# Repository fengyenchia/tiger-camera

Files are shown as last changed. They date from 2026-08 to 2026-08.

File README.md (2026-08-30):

# Tiger Camera

一台結合 ESP32-S3-CAM、手機後製與公開相簿的 DIY 相機，讓每次按下快門都能留下可下載、可分享的照片。

Tiger Camera 以 ESP32-S3-CAM 與 OV2640 為核心，拍照後透過 Wi-Fi 暫存照片。使用者掃描機身 NFC、輸入螢幕上的領取碼，就能直接在手機瀏覽器完成後製、下載，或將成品公開到網站相簿。

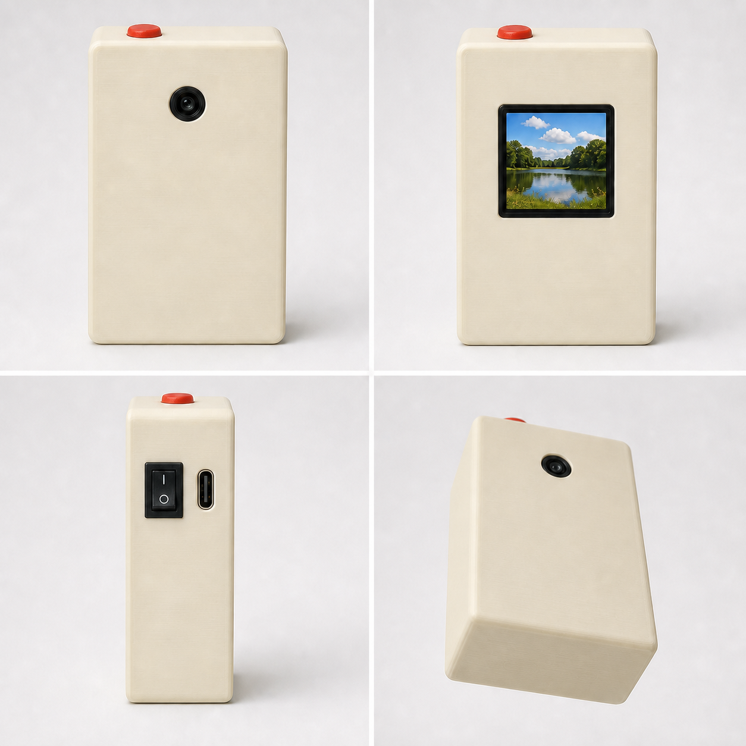
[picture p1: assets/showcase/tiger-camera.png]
Tiger Camera 外觀示意圖


## 核心特色

- 短按快門即可拍攝 JPEG，並在小型 TFT 螢幕上回顧照片
- 透過 2.4 GHz Wi-Fi 上傳私人照片草稿
- NFC 開啟領取頁，再以六位領取碼取得自己的照片
- 手機瀏覽器直接後製，不需要安裝 App
- 可選擇：
  - 拍立得白邊框
  - 拍攝日期與時間
  - 自訂文字或可愛預設文字
  - 直式 3:4、橫式 4:3、方形 1:1
  - 多種可愛風格濾鏡
- 完成圖可下載，也可以選擇公開到相簿
- 公開相片支援放大檢視與下載
- 原始照片只作為私人暫存，永久保存的是後製完成圖

## 功能

### 相機端

- 實體快門短按拍攝 JPEG，拍攝後立即在 ST7735 螢幕回顧
- 以 PSRAM 保留最新一張照片；下一次成功拍攝時覆蓋上一張
- 顯示 Wi-Fi、上傳與電池狀態，網路暫時中斷時不影響基本拍照
- 連線至指定的 2.4 GHz Wi-Fi，不需要相機自行建立 Wi-Fi 熱點

### 網站端

- NFC 導向領取頁，輸入相機顯示的六位領取碼即可取得照片
- 在手機瀏覽器完成裁切比例、拍立得框、日期、文字與風格處理
- 支援直式 3:4、橫式 4:3、方形 1:1，不改變原照片方向
- 成品可直接下載；公開後會出現在公開相簿並可放大檢視與下載
- 原始照片只在領取與後製期間保存；網站永久保存後製成品
- 公開相簿由管理員維護，管理員可重新命名或永久刪除公開照片

## 網站

- 公開網站：[tiger-camera.fengyenchia.com](https://tiger-camera.fengyenchia.com)
- 使用流程：開啟網站的 `/create` 頁面 → 輸入相機顯示的六位領取碼 → 後製 → 下載或公開
- 公開相簿：[tiger-camera.fengyenchia.com/gallery](https://tiger-camera.fengyenchia.com/gallery)

### 網站畫面

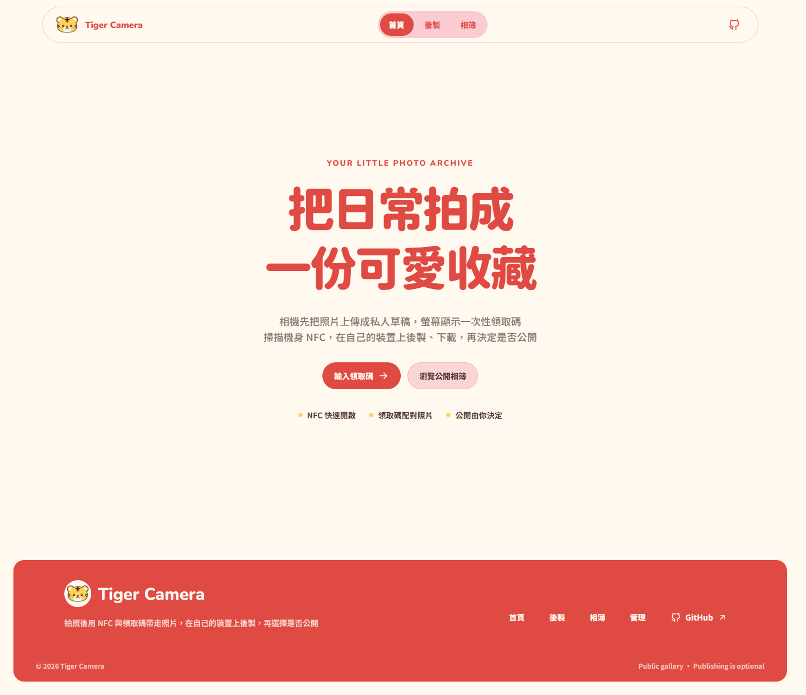
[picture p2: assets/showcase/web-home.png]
Tiger Camera 首頁


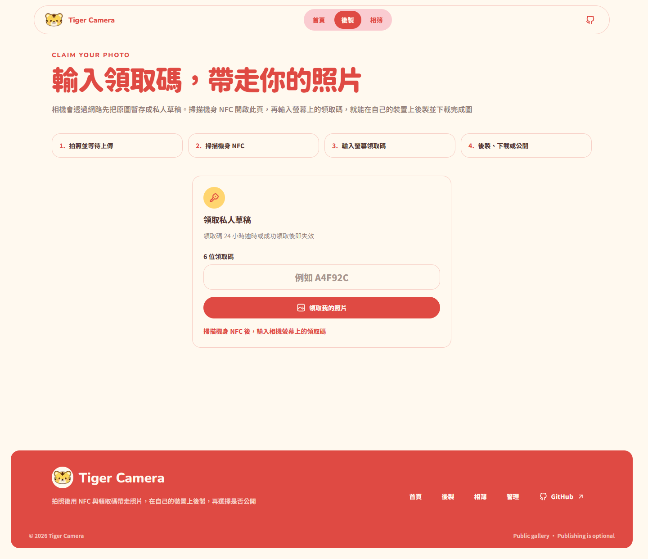
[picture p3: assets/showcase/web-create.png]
Tiger Camera 領取與後製頁


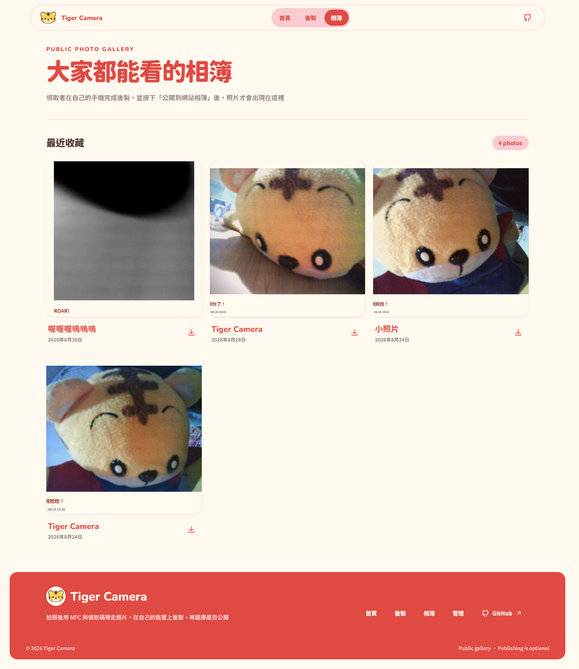
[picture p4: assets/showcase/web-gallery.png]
Tiger Camera 公開相簿


## 使用流程

```text
按下快門
    ↓
相機拍攝並連線上傳私人草稿
    ↓
掃描 NFC，開啟 Tiger Camera 網站
    ↓
輸入螢幕上的六位領取碼
    ↓
在手機選擇版型、文字與濾鏡
    ↓
下載完成圖，或公開到相簿
```

領取碼是照片配對用的一次性代碼；照片在領取前保持私人狀態，公開與否由領取者決定。

## 照片資料流程

```text
1. 按下相機快門
   ↓
2. ESP32-S3-CAM 擷取 JPEG，暫存在 PSRAM
   ↓
3. 相機以固定的裝置上傳 Token，透過 HTTPS 上傳私人草稿
   ↓
4. Backend 將原圖存入 Cloudflare R2，並在 Neon 建立草稿 metadata
   ↓
5. Backend 回傳六位領取碼；相機將領取碼顯示在螢幕上
   ↓
6. 使用者掃描 NFC、開啟 /create，輸入領取碼
   ↓
7. Backend 核發該照片的一次性領取權杖，瀏覽器取得私人原圖
   ↓
8. 使用者在手機 Canvas 完成裁切、框線、日期、文字與濾鏡
   ↓
9. 使用者下載成品，或明確選擇公開
   ↓
10. 公開時 Backend 儲存後製 JPEG、更新 metadata，並刪除私人原圖
   ↓
11. 公開相片出現在 /gallery；訪客可檢視與下載
```

原圖只用於領取與後製，不作為公開相簿內容；若使用者只下載、不公開，原圖仍會依草稿保存期限清理。

## 技術組成

| 部分 | 使用技術 |
| --- | --- |
| 相機硬體 | ESP32-S3-WROOM-1-N16R8、OV2640、ST7735 TFT、實體快門 |
| 韌體 | Arduino-ESP32、PlatformIO、PSRAM JPEG buffer |
| 前端 | Next.js、React、TypeScript、Tailwind CSS、shadcn/ui、Canvas API |
| 後端 | Next.js Route Handlers、Neon Serverless PostgreSQL、Cloudflare R2 |
| 儲存 | 原圖私人暫存；後製完成圖永久保存 |
| 電源 | 803040 LiPo、TP4056、MT3608、KCD1-11 |

## 環境需求與安裝

- Node.js 20 或以上
- pnpm 9 或以上（專案目前使用 pnpm workspace）
- 現代瀏覽器（Chrome、Edge、Safari 或 Firefox）
- 若要執行完整後端：Neon Serverless PostgreSQL 與 Cloudflare R2

在專案根目錄安裝 Web workspace 依賴：

```powershell
cd web
pnpm install
```

## 快速開始

需要 Frontend／Backend 各自的本機環境變數。請勿將密碼、Token 或雲端金鑰提交到 Git。

```powershell
cd web
pnpm install
pnpm dev
```

這會同時啟動 Frontend（`http://localhost:3000`）與 Backend（`http://localhost:3001`）。若只想啟動單一服務，也可以使用 `pnpm dev:frontend` 或 `pnpm dev:backend`。若只想查看公開介面，也可以直接使用正式網站連結。

## 部署設定

正式環境需要在部署平台設定環境變數，至少包含：

- Frontend API base URL
- Backend 公開 API URL
- Neon 資料庫連線字串
- Cloudflare R2 endpoint、bucket 與存取金鑰
- 管理員登入驗證設定
- 相機使用的固定 `DEVICE_UPLOAD_TOKEN`

這些值只應放在本機 `.env.local` 或 Vercel 等部署平台的環境變數設定中。README 不提供實際金鑰、密碼或 Token；`.gitignore` 會忽略本機秘密檔案。

## 專案結構

```text
tiger-camera/
├── firmware/
│   └── tiger-camera-v1/
│       ├── include/       # 腳位、相機、螢幕、快門、電池與網路模組
│       ├── src/           # Arduino-ESP32 韌體程式
│       ├── boards/        # ESP32-S3-CAM 板型設定
│       └── platformio.ini # PlatformIO 建置設定
├── web/
│   ├── frontend/          # 公開 Next.js 網站與手機後製介面
│   │   ├── app/           # 首頁、領取後製頁、公開相簿、管理頁
│   │   ├── api/           # Axios 前端呼叫層
│   │   ├── components/    # 共用 UI 與網站元件
│   │   └── lib/           # Canvas 圖片處理
│   ├── backend/           # 獨立部署的 Next.js API
│   │   ├── app/api/       # Route Handlers 與 API 文件頁
│   │   └── lib/           # Neon、R2、驗證與伺服器邏輯
├── enclosure/             # 外殼 CAD、STL、量測與參考圖
├── assets/                # 展示圖片與共用資產
│   └── showcase/          # README 使用的產品／網站截圖
├── bom/                   # 材料與採購清單
└── README.md              # 公開產品介紹
```

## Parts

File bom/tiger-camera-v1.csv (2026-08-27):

已購買 | category | item | recommended_model_or_keyword | detailed_specification | quantity | stage | unit_price_twd | subtotal_twd | required | listing_type | seller_or_source | shopee_url | shopee_search_url | checked_date | arrival_check | notes
V | 核心 | ESP32-S3-CAM 主板＋鏡頭 | AroundTW／GOOUUU ESP32-S3-CAM N16R8＋OV2640 | ESP32-S3-WROOM-1-N16R8；16MB Flash；8MB Octal PSRAM；OV2640 2MP；2.4GHz Wi-Fi；OTG與TTL雙USB-C；板載microSD | 1 | 先買 | 420 | 420 | yes | 直接商品頁雙相機選項 | 環島科技 | https://shopee.tw/%E3%80%90%E7%92%B0%E5%B3%B6%E7%A7%91%E6%8A%80%E3%80%91ESP32-S3-CAM-%E6%A0%B8%E5%BF%83%E9%96%8B%E7%99%BC%E6%9D%BF-%E5%8F%B0%E7%81%A3%E7%8F%BE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 | https://shopee.tw/search?keyword=ESP32-S3-CAM%20N16R8%20OV2640 | 2026-08-11 | 確認選OV2640而非OV3660；記錄PCB與N16R8標示；測TTL及OTG燒錄；韌體確認16MB Flash與8MB PSRAM | 商品頁價格區間NT$420至480；OV2640預算先列420；主板未標示LiPo充電；不得沿用AI-Thinker pinout
V | 核心 | ST7735 SPI 螢幕 | 實機 ST7735 128x128 SPI 無觸控 | 實機面板為128×128；3.3V邏輯；INITR_144GREENTAB；BGR；inversion off；面板吋數與PCB尺寸待卡尺量測 | 1 | 已驗收 | 180 | 180 | yes | 三選項商品頁 | 樂意創客官方店 | https://shopee.tw/%E3%80%90%E6%A8%82%E6%84%8F%E5%89%B5%E5%AE%A2%E5%AE%98%E6%96%B9%E5%BA%97%E3%80%91%E3%80%8A%E9%99%84%E7%99%BC%E7%A5%A8%E3%80%8B1.8%E5%90%8B-1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 | https://shopee.tw/search?keyword=ST7735%20128x128%20SPI | 2026-08-24 | 已重新確認RGB色條與方形即時預覽；仍需量螢幕對角與PCB長寬 | 實機面板是128×128；賣場共用128×160標題不可作為實機規格；外殼不可用未量測尺寸鎖定
V | 核心 | 快門按鍵（四腳版） | 6x6x5mm 四腳輕觸開關／TS-1187A 類 | 常開瞬時四腳穿孔按鍵；另購相容按鍵帽可改善手感 | 2 | 先買 | 5 | 10 | yes | 蝦皮搜尋頁 | 電子材料賣家 | https://shopee.tw/search?keyword=6x6x5mm%20%E8%BC%95%E8%A7%B8%E9%96%8B%E9%97%9C | https://shopee.tw/search?keyword=6x6x5mm%20%E8%BC%95%E8%A7%B8%E9%96%8B%E9%97%9C | 2026-08-28 | 用萬用電表確認兩側接腳與按下導通；接GPIO1與GND | 保留作為開發版或小體積安裝方案
V | 核心 | 快門按鍵（面板版） | 060009 兩腳面板固定式自復位按鈕（125V 3A） | 兩腳無正負極；螺牙加螺帽固定；按下導通且放開復位；外殼開孔尺寸仍以實物量測 | 1 | 已驗收 |  |  | conditional | 蝦皮搜尋頁 | 電子材料賣家 | https://shopee.tw/search | https://shopee.tw/search | 2026-08-28 | 已接GPIO1與GND實測；按一下成功拍照且放開復位；E0仍須量螺牙直徑、面板開孔及後方深度 | 與四腳版並列保留；125V 3A是開關接點額定標示，不是本專案供電電壓
V | 開發 | 接線與麵包板 | 400孔麵包板＋2.54mm 杜邦線＋短跳線 | 公對公／公對母線；保持 TFT SPI 線短 | 1批 | 先買 | 100 | 100 | conditional | 蝦皮搜尋頁 | 台灣出貨電子材料賣家 | https://shopee.tw/search | https://shopee.tw/search | 2026-08-11 | 抽查導通與夾持力；TFT 線先控制在10cm內 | 已有庫存可省
V | 分享 | NFC 被動貼紙 | NTAG213 圓形防水貼紙（我買 NTAG215） | NDEF可寫入；保存 https://tiger-camera.fengyenchia.com/create；不需相機端NFC硬體 | 1 | NFC階段 | 20 | 20 | yes | 蝦皮搜尋頁 | 台灣出貨 NFC 賣家 | https://shopee.tw/search?keyword=NTAG213%20NFC%20%E8%B2%BC%E7%B4%99 | https://shopee.tw/search?keyword=NTAG213%20NFC%20%E8%B2%BC%E7%B4%99 | 2026-08-11 | 用 NFC Tools 寫入並以 iPhone／Android 各測一次；不要先永久鎖定 | NFC 只開啟正式網站；每張照片領取碼顯示在相機螢幕
 | 儲存 | microSD 記憶卡 | 4GB microSD／FAT32 選配 | 只在需要相機端關機保存／離線JSON／裝置端多照片相簿時購買；GPIO38至40保留給板載SD | 1 | 未來選配 | 100 | 100 | no | 蝦皮搜尋頁 | 可靠品牌賣家 | https://shopee.tw/search?keyword=4GB%20microSD%20FAT32 | https://shopee.tw/search?keyword=4GB%20microSD%20FAT32 | 2026-08-11 | 完整讀寫測試並確認與TFT及快門共存 | V1不買；裝置最新照片只存PSRAM；雲端永久相簿不依賴microSD；未來可再依實機確認支援容量
v | 電源 | LiPo 電池 | 環島科技 803040 3.7V 1000mAh 單節聚合物鋰電池 | 標稱3.7V滿電4.2V；標準充電0.5C/500mA；最大充電1C/1A；最大放電1C/1A；保護IC允許最大電流2A；尺寸8.0±0.3×30±0.5×40±1mm，含保護板與導線可能更長 | 1 | P0已選 | 220 | 220 | yes | 蝦皮商品頁 | 環島科技 | https://shopee.tw/%E3%80%90%E7%92%B0%E5%B3%B6%E7%A7%91%E6%8A%80%E3%80%913.7V-%E8%81%9A%E5%90%88%E7%89%A9%E9%8B%B0%E9%9B%BB%E6%B1%A0-803040-%E5%8F%B0%E7%81%A3%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 | https://shopee.tw/search?keyword=803040%201000mAh%203.7V%20%E9%8B%B0%E9%9B%BB%E6%B1%A0 | 2026-08-24 | 商品規格已提供：標準充電0.5C/500mA、最大充電1C/1A、最大放電1C/1A、保護IC允許最大電流2A；到貨仍確認實物標籤、保護板、接頭、極性與尺寸；先量到貨電壓再接模組 | 803040厚度較503040增加約3mm；容量提高但外殼與電池艙需重新量測
v | 電源 | LiPo充電板 | 環島科技 TP4056 Type-C 1A 鋰電池充電保護二合一 | Type-C輸入；商品標示1A；電池最大充電1A；4.2V CC/CV與保護 | 1 | P0已選 | 10 | 10 | yes | 蝦皮商品頁 | 環島科技 | https://shopee.tw/%E3%80%90%E7%92%B0%E5%B3%B6%E7%A7%91%E6%8A%80%E3%80%91%E6%96%B0%E6%AC%BETP4056-1A%E9%8B%B0%E9%9B%BB%E6%B1%A0%E5%85%85%E9%9B%BB%E6%9D%BF%E6%A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 | https://shopee.tw/search?keyword=TP4056%20Type-C%20500mA%20%E9%8B%B0%E9%9B%BB%E6%B1%A0 | 2026-08-24 | 首次量測實際充電電流與溫度；燙手就停止
v | 電源 | 5V升壓板 | 環島科技 MT3608 DC-DC 2A可調升壓模組 | 輸入2至24V；輸出可調；使用前先以萬用電表調至5.0V；2A為賣家最大標稱 | 1 | P0已選 | 15 | 15 | yes | 蝦皮商品頁 | 環島科技 | https://shopee.tw/-%E7%92%B0%E5%B3%B6%E7%A7%91%E6%8A%80-MT3608-DC-DC%E5%8D%87%E5%A3%93%E6%A8%A1%E5%A1%8A2A%E5%8D%87%E5%A3%93%E6%9D%BF%E8%BC%B8%E5%85%A5%E9%9B%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 | https://shopee.tw/search?keyword=MT3608%205V%20%E5%8D%87%E5%A3%93 | 2026-08-24 | 開機前先量空載5V；切斷升壓輸入的電源開關需放在TP4056與MT3608之間
v | 電源 | 電源開關 | 環島科技 KCD1-11 小船型 1P 三腳開關 | 商品標示3A/250V、6A/125V；確認腳位後以中間／切換腳控制MT3608 IN+；第三腳依版本用途處理 | 1 | P0已選 | 15 | 15 | yes | 蝦皮商品頁 | 環島科技 | https://shopee.tw/%E3%80%90%E7%92%B0%E5%B3%B6%E7%A7%91%E6%8A%80-%E5%B0%8F%E8%88%B9%E5%9E%8B%E9%96%8B%E9%97%9C-%E5%B0%8F%E5%B0%8F%E6%B4%9B%E5%8F%AF%E9%96%8B%E9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 | https://shopee.tw/search?keyword=KCD1-11%20%E9%96%8B%E9%97%9C | 2026-08-24 | 外殼需開矩形孔；先以DT-830D通斷檔確認腳位；不可只依外觀接線
v | 電源 | 電池電壓分壓組 | 100kΩ×2（0.1µF陶瓷電容選配） | KCD1-11開關後正極經100kΩ到GPIO3；GPIO3再經100kΩ到OUT-/GND；不可從常時帶電OUT+直接送入GPIO；不能直接接LiPo到GPIO | 1組 | P0.1 | 5 | 5 | yes | 電子材料搜尋頁 | 台灣電子材料賣家 | https://shopee.tw/search?keyword=100k%20%E9%9B%BB%E9%98%BB | https://shopee.tw/search?keyword=100k%20%E9%9B%BB%E9%98%BB | 2026-08-27 | 用萬用電表確認阻值；接線後驗證10次冷啟動與TFT讀值 | GPIO3為strapping pin；0.1µF可不裝；只可用高阻抗分壓並以DT-830D校正
 | 外殼 | M2 五金 | M2 熱熔螺母 OD3.2×L3mm＋M2 機牙螺絲組 | M2×6／8／10mm 少量；先印孔徑測試片 | 1批 | CAD後 | 120 | 120 | yes | 蝦皮搜尋頁 | 3D列印五金賣家 | https://shopee.tw/search | https://shopee.tw/search | 2026-08-11 | 先印孔徑測試片再鎖定 CAD 孔位 | 基本兩片式相機殼不做角色裝飾
 | 外殼 | 透明保護片 | PET透明片0.3至0.5mm | 可裁切；螢幕可視區需無霧化與刮痕 | 1 | CAD後 | 50 | 50 | no | 蝦皮搜尋頁 | 模型材料賣家 | https://shopee.tw/search?keyword=PET%20%E9%80%8F%E6%98%8E%E7%89%87%200.5mm | https://shopee.tw/search?keyword=PET%20%E9%80%8F%E6%98%8E%E7%89%87%200.5mm | 2026-08-11 | 在亮屏上檢查反光／霧度 | 螢幕內縮且受保護時可省
 | 外殼 | 3D列印材料 | PETG 1.75mm 少量或外包基本殼 | 兩片式矩形功能殼；先用現有材料或外包小量列印 | 1批 | 功能完成後 | 300 | 300 | yes | 蝦皮搜尋頁 | 3D列印耗材或代印賣家 | https://shopee.tw/search?keyword=PETG%201.75mm%203D%E5%88%97%E5%8D%B0%20%E4%BB%A3%E5%8D%B0 | https://shopee.tw/search?keyword=PETG%201.75mm%203D%E5%88%97%E5%8D%B0%20%E4%BB%A3%E5%8D%B0 | 2026-08-11 | 先印平面定位板與功能殼 | 已有耗材可省；不做虎頭造型可顯著減少列印量

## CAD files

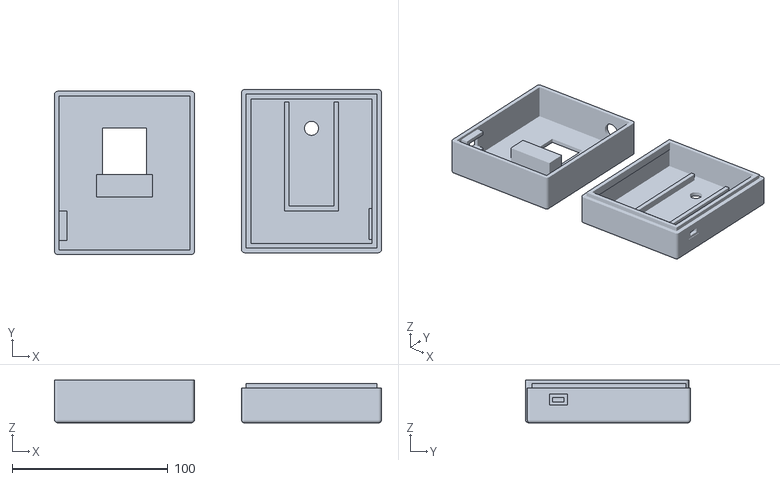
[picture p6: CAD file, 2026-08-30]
enclosure/stl/v1.stl
210.2 x 106.2 x 27.6

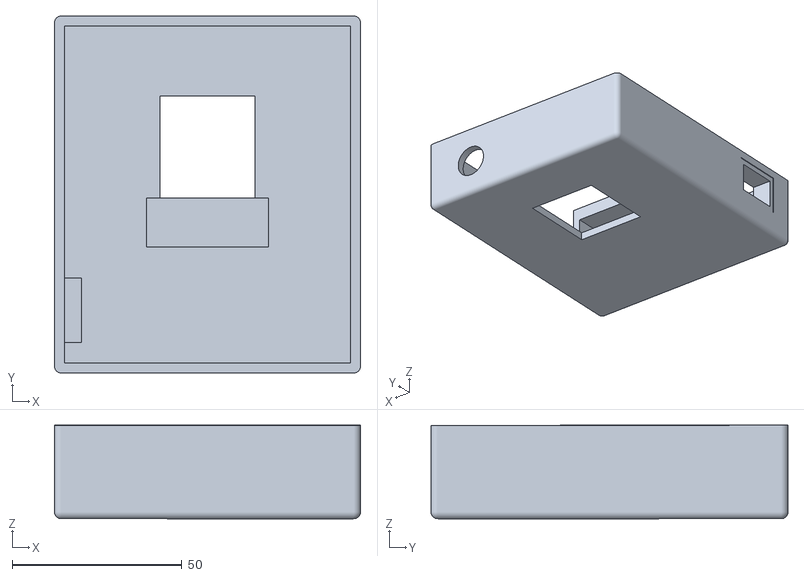
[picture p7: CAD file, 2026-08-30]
enclosure/stl/後蓋.stl
90.0 x 105.0 x 27.5

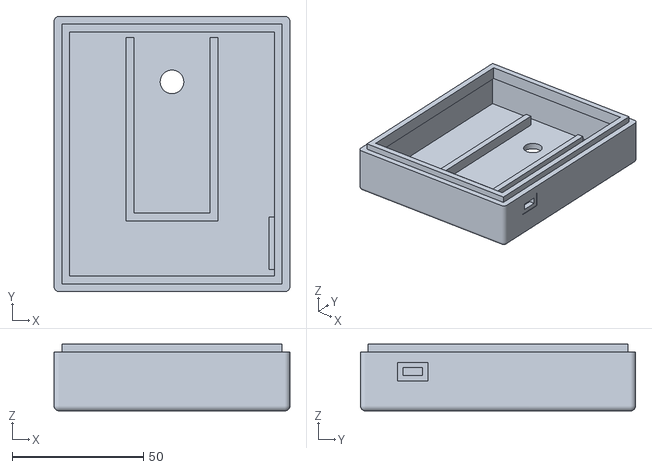
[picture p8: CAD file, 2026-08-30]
enclosure/stl/前蓋.stl
90.0 x 105.0 x 25.5

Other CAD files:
enclosure/v1.blend

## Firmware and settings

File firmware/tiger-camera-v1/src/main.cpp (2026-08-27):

#include <Arduino.h>
#include "esp_heap_caps.h"

#include "app_config.h"
#include "battery_monitor.h"
#include "board_pins.h"
#include "camera_controller.h"
#include "display_controller.h"
#include "latest_photo_buffer.h"
#include "network_manager.h"
#include "shutter_button.h"
#include "upload_manager.h"

enum class CameraState {
  booting,
  liveView,
  capturing,
  copying,
  review,
  uploadNotice,
  claimReady,
  error,
};

CameraController camera;
DisplayController display;
LatestPhotoBuffer latestPhoto;
NetworkManager network;
UploadManager uploader;
ShutterButton shutter(BoardPins::shutter, AppConfig::shutterDebounceMs);
BatteryMonitor battery(BoardPins::batterySense);

CameraState state = CameraState::booting;
unsigned long stateStartedMs = 0;
unsigned long lastPreviewMs = 0;
uint32_t latestUploadGeneration = 0;
bool latestClaimAvailable = false;
char latestClaimCode[7] = {};
char latestClaimExpiresAt[25] = {};

void enterState(CameraState next) {
  state = next;
  stateStartedMs = millis();
}

void printMemoryReport() {
  Serial.printf("[board] flash: %u bytes\n",
                static_cast<unsigned>(ESP.getFlashChipSize()));
  Serial.printf("[board] psram detected: %s\n", psramFound() ? "yes" : "no");
  Serial.printf("[board] psram total: %u bytes\n",
                static_cast<unsigned>(ESP.getPsramSize()));
  Serial.printf("[board] psram free: %u bytes\n",
                static_cast<unsigned>(heap_caps_get_free_size(MALLOC_CAP_SPIRAM)));
  Serial0.printf("[board] flash: %u bytes\n",
                 static_cast<unsigned>(ESP.getFlashChipSize()));
  Serial0.printf("[board] psram detected: %s\n", psramFound() ? "yes" : "no");
  Serial0.printf("[board] psram total: %u bytes\n",
                 static_cast<unsigned>(ESP.getPsramSize()));
  Serial0.printf(
      "[board] psram free: %u bytes\n",
      static_cast<unsigned>(heap_caps_get_free_size(MALLOC_CAP_SPIRAM)));
}

void showLatestPhoto() {
  if (!latestPhoto.lock(pdMS_TO_TICKS(1000))) {
    display.showStatus("BUFFER BUSY");
    delay(1000);
    enterState(CameraState::error);
    return;
  }

  const bool rendered = display.drawJpeg(latestPhoto.dataUnsafe(),
                                         latestPhoto.sizeUnsafe());
  latestPhoto.unlock();
  if (!rendered) {
    display.showStatus("JPEG ERROR");
    delay(1000);
    enterState(CameraState::error);
    return;
  }
  const BatteryReading& batteryReading = battery.reading();
  display.showBatteryOverlay(batteryReading.volts, batteryReading.percent,
                             batteryReading.valid);
  enterState(CameraState::review);
}

void pollUploadResult() {
  uint32_t generation = 0;
  char claimCode[7] = {};
  char expiresAt[25] = {};
  if (!uploader.takeClaimCode(&generation, claimCode, sizeof(claimCode),
                              expiresAt, sizeof(expiresAt))) {
    return;
  }
  if (generation != latestUploadGeneration) {
    Serial.printf("[upload] ignored stale claim generation=%lu latest=%lu\n",
                  generation, latestUploadGeneration);
    Serial0.printf("[upload] ignored stale claim generation=%lu latest=%lu\n",
                   generation, latestUploadGeneration);
    return;
  }
  strlcpy(latestClaimCode, claimCode, sizeof(latestClaimCode));
  strlcpy(latestClaimExpiresAt, expiresAt, sizeof(latestClaimExpiresAt));
  latestClaimAvailable = true;
}

void showUploadNotice() {
  const UploadStatus uploadStatus = uploader.status();
  switch (uploadStatus.phase) {
    case UploadPhase::waitingForWifi:
      display.showStatus("WAITING WIFI", "photo kept");
      delay(1000);
      break;
    case UploadPhase::waitingForTime:
      display.showStatus("SYNCING TIME", "photo kept");
      delay(1000);
      break;
    case UploadPhase::configurationError:
      display.showStatus("UPLOAD OFF", "check secrets");
      delay(1000);
      break;
    case UploadPhase::authenticationError:
      display.showStatus("DEVICE ERROR", "credential");
      delay(1000);
      break;
    case UploadPhase::serverRejected:
      display.showStatus("UPLOAD ERROR", "check serial");
      delay(1000);
      break;
    case UploadPhase::memoryError:
      display.showStatus("UPLOAD ERROR", "photo kept");
      delay(1000);
      break;
    case UploadPhase::retrying:
      display.showStatus("UPLOAD RETRY", "photo kept");
      delay(1000);
      break;
    default:
      display.showStatus("UPLOADING", "private draft");
      delay(1000);
      break;
  }
  enterState(CameraState::uploadNotice);
}

void showLatestClaim() {
  display.showClaimCode(latestClaimCode);
  Serial.printf("[claim] code=%s expires=%s\n", latestClaimCode,
                latestClaimExpiresAt);
  Serial0.printf("[claim] code=%s expires=%s\n", latestClaimCode,
                 latestClaimExpiresAt);
  enterState(CameraState::claimReady);
}

void capturePhoto() {
  latestClaimAvailable = false;
  enterState(CameraState::capturing);
  display.showStatus("CAPTURING");
  delay(1000);

  if (AppConfig::captureFrameSize != AppConfig::previewFrameSize) {
    if (!camera.setFrameSize(AppConfig::captureFrameSize)) {
      display.showStatus("CAMERA ERROR", "resolution");
      delay(1000);
      enterState(CameraState::error);
      return;
    }

    // Only discard transition frames when the sensor mode actually changes.
    camera.flushFrames(AppConfig::captureSettleFrames);
  }
  camera_fb_t* frame = camera.acquireFrame();
  if (frame == nullptr || frame->format != PIXFORMAT_JPEG || frame->len == 0) {
    const char* reason = frame == nullptr
                             ? "no framebuffer"
                             : (frame->format != PIXFORMAT_JPEG ? "not JPEG"
                                                                : "empty JPEG");
    Serial.printf("[photo] capture failed: %s\n", reason);
    Serial0.printf("[photo] capture failed: %s\n", reason);
    camera.releaseFrame(frame);
    if (AppConfig::captureFrameSize != AppConfig::previewFrameSize) {
      camera.setFrameSize(AppConfig::previewFrameSize);
      camera.flushFrames(AppConfig::previewSettleFrames);
    }
    display.showStatus("CAPTURE ERROR", reason);
    delay(1000);
    enterState(CameraState::error);
    return;
  }

  enterState(CameraState::copying);
  const size_t capturedSize = frame->len;
  const uint16_t capturedWidth = frame->width;
  const uint16_t capturedHeight = frame->height;
  const uint32_t capturedMillis = millis();
  const bool copied = latestPhoto.replace(frame->buf, frame->len);

  // The camera framebuffer is returned only after the JPEG is fully copied.
  camera.releaseFrame(frame);
  if (AppConfig::captureFrameSize != AppConfig::previewFrameSize) {
    camera.setFrameSize(AppConfig::previewFrameSize);
    camera.flushFrames(AppConfig::previewSettleFrames);
  }

  if (!copied) {
    display.showStatus("PSRAM ERROR", "old photo kept");
    delay(1000);
    enterState(CameraState::error);
    return;
  }

  Serial.printf("[photo] captured %ux%u %u bytes; free PSRAM %u bytes\n",
                static_cast<unsigned>(capturedWidth),
                static_cast<unsigned>(capturedHeight),
                static_cast<unsigned>(capturedSize),
                static_cast<unsigned>(
                    heap_caps_get_free_size(MALLOC_CAP_SPIRAM)));
  Serial0.printf("[photo] captured %ux%u %u bytes; free PSRAM %u bytes\n",
                 static_cast<unsigned>(capturedWidth),
                 static_cast<unsigned>(capturedHeight),
                 static_cast<unsigned>(capturedSize),
                 static_cast<unsigned>(
                     heap_caps_get_free_size(MALLOC_CAP_SPIRAM)));

  // A successful local capture invalidates every older claim immediately,
  // even if allocating the new upload snapshot fails.
  latestUploadGeneration = UINT32_MAX;
  bool queued = false;
  if (latestPhoto.lock(pdMS_TO_TICKS(1000))) {
    queued = uploader.queuePhoto(
        latestPhoto.dataUnsafe(), latestPhoto.sizeUnsafe(), capturedWidth,
        capturedHeight, capturedMillis, &latestUploadGeneration);
    latestPhoto.unlock();
  }
  if (!queued) {
    Serial.println("[upload] could not queue photo; local JPEG remains available");
    Serial0.println("[upload] could not queue photo; local JPEG remains available");
  }
  showLatestPhoto();
}

void drawLivePreview() {
  camera_fb_t* frame = camera.acquireFrame();
  if (frame == nullptr) {
    Serial.println("[preview] frame unavailable");
    return;
  }
  if (frame->format == PIXFORMAT_JPEG) {
    display.drawJpeg(frame->buf, frame->len);
    const BatteryReading& batteryReading = battery.reading();
    display.showBatteryOverlay(batteryReading.volts, batteryReading.percent,
                               batteryReading.valid);
  }
  camera.releaseFrame(frame);
}

void setup() {
  Serial.begin(115200);

  // 等待 USB 串口連線成功（最多等 3 秒避免卡死）
  unsigned long start = millis();
  while (!Serial && (millis() - start < 3000)) {
    delay(10);
  }

  Serial.println("ESP32-S3 Camera Booting...");

  Serial0.begin(115200);
  delay(800);

  display.begin();
  battery.begin();

  // ─── 頁面 1: 四色色塊測試（停留 1 秒）───
  display.showColorTest();
  delay(1000);

  // ─── 頁面 2: 品牌主視覺（停留 2.0 秒）───
  display.showSplashPage("TIGER CAM", "by Yen-Chia Feng");
  delay(2000);

  // ─── 頁面 3: 終端機 Log 與逐項初始化 ───
  display.showBootLogPage();
  delay(400);

  // 1. PSRAM 檢測
  if (!psramFound() || ESP.getPsramSize() == 0) {
    display.appendBootLog("PSRAM", "FAIL", 25);
    delay(1500);
    display.showStatus("PSRAM ERROR", "not detected");
    enterState(CameraState::error);
    return;
  }
  display.appendBootLog("PSRAM", "OK", 25);
  printMemoryReport();
  delay(600);

  // 2. 緩衝區初始化
  if (!latestPhoto.begin()) {
    display.appendBootLog("BUFFER", "FAIL", 50);
    delay(1500);
    display.showStatus("MUTEX ERROR");
    enterState(CameraState::error);
    return;
  }
  display.appendBootLog("BUFFER", "OK", 50);
  delay(600);

  // 3. 網路與上傳管理器
  network.begin();
  if (!uploader.begin(&network)) {
    Serial.println("[upload] background task unavailable; camera remains local-only");
    Serial0.println("[upload] background task unavailable; camera remains local-only");
  }
  display.appendBootLog("NETWORK", "OK", 75);
  delay(600);

  // 4. OV2640 相機模組
  if (!camera.begin()) {
    display.appendBootLog("CAMERA", "FAIL", 100);
    delay(1500);
    display.showStatus("CAMERA ERROR", "init failed");
    enterState(CameraState::error);
    return;
  }
  display.appendBootLog("CAMERA", "OK", 100);
  delay(1000);

  // ─── 完成並提示拍照 ───
  shutter.begin();
  display.showStatus("READY", "press shutter");
  delay(1800);
  shutter.discardPending();
  enterState(CameraState::liveView);
}

void loop() {
  const unsigned long now = millis();
  battery.loop();
  network.loop();
  pollUploadResult();

  if (state == CameraState::liveView) {
    if (latestClaimAvailable) {
      showLatestClaim();
      return;
    }
    if (shutter.pressed()) {
      capturePhoto();
      return;
    }
    if (now - lastPreviewMs >= AppConfig::previewIntervalMs) {
      lastPreviewMs = now;
      drawLivePreview();
    }
    return;
  }

  if (state == CameraState::review &&
      now - stateStartedMs >= AppConfig::reviewDurationMs) {
    // Capturing and review intentionally ignore presses and switch bounce.
    shutter.discardPending();
    if (latestClaimAvailable) {
      showLatestClaim();
    } else {
      showUploadNotice();
    }
    return;
  }

  if (state == CameraState::uploadNotice &&
      now - stateStartedMs >= AppConfig::uploadNoticeDurationMs) {
    shutter.discardPending();
    if (latestClaimAvailable) {
      showLatestClaim();
    } else {
      enterState(CameraState::liveView);
    }
    return;
  }

  if (state == CameraState::claimReady) {
    // The first press dismisses the code and returns to live view. A later
    // press from live view captures the next photo, preventing an accidental
    // shot while the owner is only trying to leave the claim screen.
    if (shutter.pressed()) {
      latestClaimAvailable = false;
      enterState(CameraState::liveView);
    }
    return;
  }

  if (state == CameraState::error &&
      now - stateStartedMs >= AppConfig::errorDurationMs) {
    if (esp_camera_sensor_get() != nullptr) {
      camera.setFrameSize(AppConfig::previewFrameSize);
      camera.flushFrames(AppConfig::previewSettleFrames);
      shutter.discardPending();
      enterState(CameraState::liveView);
    }
  }

  delay(5);
}

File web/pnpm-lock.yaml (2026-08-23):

lockfileVersion: '9.0'

settings:
  autoInstallPeers: true
  excludeLinksFromLockfile: false

importers:

  .: {}

  backend:
    dependencies:
      '@aws-sdk/client-s3':
        specifier: ^3.1110.0
        version: 3.1110.0
      '@aws-sdk/s3-request-presigner':
        specifier: ^3.1110.0
        version: 3.1110.0
      '@neondatabase/serverless':
        specifier: ^1.1.0
        version: 1.1.0
      bcryptjs:
        specifier: ^3.0.3
        version: 3.0.3
      jose:
        specifier: ^6.2.8
        version: 6.2.8
      next:
        specifier: 16.3.0
        version: 16.3.0(@babel/core@7.29.7)(@types/node@20.19.43)(react-dom@19.2.8(react@19.2.8))(react@19.2.8)
      next-swagger-doc:
        specifier: ^0.4.1
        version: 0.4.1(next@16.3.0(@types/node@20.19.43)(react-dom@19.2.8(react@19.2.8))(react@19.2.8))(openapi-types@12.1.3)
      react:
        specifier: 19.2.8
        version: 19.2.8
      react-dom:
        specifier: 19.2.8
        version: 19.2.8(react@19.2.8)
      server-only:
        specifier: ^0.0.1
        version: 0.0.1
      swagger-ui-dist:
        specifier: ^5.32.13
        version: 5.32.13
    devDependencies:
      '@types/node':
        specifier: ^20
        version: 20.19.43
      '@types/react':
        specifier: ^19
        version: 19.2.18
      '@types/react-dom':
        specifier: ^19
        version: 19.2.4(@types/react@19.2.18)
      '@types/swagger-ui-dist':
        specifier: ^3.30.6
        version: 3.30.6
      eslint:
        specifier: ^9
        version: 9.39.5(jiti@2.7.0)
      eslint-config-next:
        specifier: 16.3.0
        version: 16.3.0(eslint@9.39.5(jiti@2.7.0))(typescript@5.1.3)
      typescript:
        specifier: ^5.1.3
        version: 5.1.3

  frontend:
    dependencies:
      '@radix-ui/react-checkbox':
        specifier: ^1.3.11
        version: 1.3.11(@types/react-dom@19.2.4(@types/react@19.2.18))(@types/react@19.2.18)(react-dom@19.2.8(react@19.2.8))(react@19.2.8)
      '@radix-ui/react-dialog':
        specifier: ^1.1.23
        version: 1.1.23(@types/react-dom@19.2.4(@types/react@19.2.18))(@types/react@19.2.18)(react-dom@19.2.8(react@19.2.8))(react@19.2.8)
      '@radix-ui/react-radio-group':
        specifier: ^1.4.7
        version: 1.4.7(@types/react-dom@19.2.4(@types/react@19.2.18))(@types/react@19.2.18)(react-dom@19.2.8(react@19.2.8))(react@19.2.8)
      '@radix-ui/react-select':
        specifier: ^2.3.7
        version: 2.3.7(@types/react-dom@19.2.4(@types/react@19.2.18))(@types/react@19.2.18)(react-dom@19.2.8(react@19.2.8))(react@19.2.8)
      '@radix-ui/react-slider':
        specifier: ^1.4.7
        version: 1.4.7(@types/react-dom@19.2.4(@types/react@19.2.18))(@types/react@19.2.18)(react-dom@19.2.8(react@19.2.8))(react@19.2.8)
      '@tabler/icons-react':
        specifier: ^3.46.0
        version: 3.46.0(react@19.2.8)
      axios:
        specifier: ^1.19.0
        version: 1.19.0(supports-color@7.1.0)
      class-variance-authority:
        specifier: ^0.7.1
        version: 0.7.1
      clsx:
        specifier: ^2.1.1
        version: 2.1.1
      motion:
        specifier: ^13.1.0
        version: 13.1.0(react-dom@19.2.8(react@19.2.8))(react@19.2.8)
      next:
        specifier: 16.3.0
        version: 16.3.0(@babel/core@7.29.7)(@types/node@20.19.43)(react-dom@19.2.8(react@19.2.8))(react@19.2.8)
      react:
        specifier: 19.2.8
        version: 19.2.8
      react-dom:
        specifier: 19.2.8
        version: 19.2.8(react@19.2.8)
      tailwind-merge:
        specifier: ^3.6.0
        version: 3.6.0
    devDependencies:
      '@tailwindcss/postcss':
        specifier: ^4
        version: 4.3.3
      '@types/node':
        specifier: ^20
        version: 20.19.43
      '@types/react':
        specifier: ^19
        version: 19.2.18
      '@types/react-dom':
        specifier: ^19
        version: 19.2.4(@types/react@19.2.18)
      eslint:
        specifier: ^9
        version: 9.39.5(jiti@2.7.0)(supports-color@7.1.0)
      eslint-config-next:
        specifier: 16.3.0
        version: 16.3.0(@typescript-eslint/parser@8.66.0(eslint@9.39.5(jiti@2.7.0)(supports-color@7.1.0))(supports-color@7.1.0)(typescript@5.1.3))(eslint@9.39.5(jiti@2.7.0)(supports-color@7.1.0))(supports-color@7.1.0)(typescript@5.1.3)
      tailwindcss:
        specifier: ^4
        version: 4.3.3
      typescript:
        specifier: ^5.1.3
        version: 5.1.3
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

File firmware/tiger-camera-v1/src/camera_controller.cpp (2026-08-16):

#include "camera_controller.h"

#include <Arduino.h>

#include "app_config.h"
#include "board_pins.h"

bool CameraController::begin() {
  camera_config_t config{};
  config.ledc_channel = LEDC_CHANNEL_0;
  config.ledc_timer = LEDC_TIMER_0;
  config.pin_d0 = BoardPins::cameraY2;
  config.pin_d1 = BoardPins::cameraY3;
  config.pin_d2 = BoardPins::cameraY4;
  config.pin_d3 = BoardPins::cameraY5;
  config.pin_d4 = BoardPins::cameraY6;
  config.pin_d5 = BoardPins::cameraY7;
  config.pin_d6 = BoardPins::cameraY8;
  config.pin_d7 = BoardPins::cameraY9;
  config.pin_xclk = BoardPins::cameraXclk;
  config.pin_pclk = BoardPins::cameraPclk;
  config.pin_vsync = BoardPins::cameraVsync;
  config.pin_href = BoardPins::cameraHref;
  config.pin_sccb_sda = BoardPins::cameraSiod;
  config.pin_sccb_scl = BoardPins::cameraSioc;
  config.pin_pwdn = BoardPins::cameraPowerDown;
  config.pin_reset = BoardPins::cameraReset;
  config.xclk_freq_hz = 20000000;
  config.pixel_format = PIXFORMAT_JPEG;
  // Framebuffer allocation happens during esp_camera_init(). Allocate for the
  // largest V1 capture size, then lower only the sensor output for live view.
  // Initializing at preview size can leave buffers too small for a later XGA
  // frame and causes esp_camera_fb_get() to return null.
  config.frame_size = AppConfig::captureFrameSize;
  config.jpeg_quality = AppConfig::jpegQuality;
  config.fb_count = 2;
  config.grab_mode = CAMERA_GRAB_LATEST;
  config.fb_location = CAMERA_FB_IN_PSRAM;

  const esp_err_t result = esp_camera_init(&config);
  if (result != ESP_OK) {
    Serial.printf("[camera] init failed: 0x%x\n", result);
    Serial0.printf("[camera] init failed: 0x%x\n", result);
    return false;
  }

  sensor_t* sensor = esp_camera_sensor_get();
  if (sensor == nullptr) {
    Serial.println("[camera] sensor unavailable");
    esp_camera_deinit();
    return false;
  }

  bool tuningApplied = true;
  tuningApplied &= sensor->set_framesize(sensor, AppConfig::previewFrameSize) == 0;
  tuningApplied &= sensor->set_whitebal(sensor, 1) == 0;
  tuningApplied &= sensor->set_awb_gain(sensor, 1) == 0;
  tuningApplied &= sensor->set_wb_mode(sensor, 0) == 0;
  tuningApplied &= sensor->set_exposure_ctrl(sensor, 1) == 0;
  tuningApplied &=
      sensor->set_aec2(sensor, AppConfig::sensorAdvancedExposure) == 0;
  tuningApplied &= sensor->set_gain_ctrl(sensor, 1) == 0;
  tuningApplied &=
      sensor->set_gainceiling(sensor, AppConfig::sensorGainCeiling) == 0;
  tuningApplied &=
      sensor->set_brightness(sensor, AppConfig::sensorBrightness) == 0;
  tuningApplied &= sensor->set_contrast(sensor, AppConfig::sensorContrast) == 0;
  tuningApplied &=
      sensor->set_saturation(sensor, AppConfig::sensorSaturation) == 0;
  tuningApplied &=
      sensor->set_ae_level(sensor, AppConfig::sensorAutoExposureLevel) == 0;
  tuningApplied &= sensor->set_bpc(sensor, 1) == 0;
  tuningApplied &= sensor->set_wpc(sensor, 1) == 0;
  tuningApplied &= sensor->set_raw_gma(sensor, 1) == 0;
  tuningApplied &= sensor->set_lenc(sensor, 1) == 0;

  Serial.printf("[camera] ready, PID=0x%02x, tuning=%s\n", sensor->id.PID,
                tuningApplied ? "applied" : "partial");
  Serial0.printf("[camera] ready, PID=0x%02x, tuning=%s\n", sensor->id.PID,
                 tuningApplied ? "applied" : "partial");
  return true;
}

camera_fb_t* CameraController::acquireFrame() {
  return esp_camera_fb_get();
}

void CameraController::releaseFrame(camera_fb_t* frame) {
  if (frame != nullptr) {
    esp_camera_fb_return(frame);
  }
}

bool CameraController::setFrameSize(framesize_t size) {
  sensor_t* sensor = esp_camera_sensor_get();
  return sensor != nullptr && sensor->set_framesize(sensor, size) == 0;
}

void CameraController::flushFrames(unsigned char count) {
  for (unsigned char index = 0; index < count; ++index) {
    camera_fb_t* frame = acquireFrame();
    releaseFrame(frame);
  }
}

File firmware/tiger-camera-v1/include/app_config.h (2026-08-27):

#pragma once

#include "esp_camera.h"

namespace AppConfig {

// Keep preview and capture in the same sensor mode. Physical tests showed that
// switching from VGA to UXGA restarts exposure and leaves the saved JPEG badly
// underexposed even after six discarded frames. XGA provides 2.56x the pixels
// of VGA without changing sensor mode at shutter time.
constexpr framesize_t previewFrameSize = FRAMESIZE_XGA;
constexpr framesize_t captureFrameSize = FRAMESIZE_XGA;
constexpr unsigned char captureSettleFrames = 0;
constexpr unsigned char previewSettleFrames = 0;
constexpr int jpegQuality = 8;
constexpr unsigned long previewIntervalMs = 180;
constexpr unsigned long reviewDurationMs = 3500;
constexpr unsigned long errorDurationMs = 1500;
constexpr unsigned long shutterDebounceMs = 35;

// P0.1 battery meter. The 100k/100k divider scales the protected LiPo output
// to one half before it reaches ADC1. `analogReadMilliVolts()` is calibrated
// by Arduino-ESP32; the final factor is intentionally configurable so it can
// be matched to the DT-830D after the divider is fitted.
constexpr unsigned long batterySampleIntervalMs = 1000;
constexpr uint8_t batterySampleCount = 16;
constexpr float batteryDividerRatio = 2.0f;
// Calibrated on 2026-08-28: DT-830D measured 4.00 V while the uncorrected TFT
// reading was 3.80 V, giving 4.00 / 3.80 = 1.0526.
constexpr float batteryVoltageCalibration = 1.0526f;

// Gate L0 networking stays independent from the camera state machine. A
// failed hotspot or upload must never reboot or disable local capture.
constexpr unsigned long wifiConnectTimeoutMs = 12000;
constexpr unsigned long wifiRetryInitialMs = 2000;
constexpr unsigned long wifiRetryMaximumMs = 60000;
constexpr unsigned long uploadRetryInitialMs = 2000;
constexpr unsigned long uploadRetryMaximumMs = 60000;
constexpr unsigned long uploadNoticeDurationMs = 1200;
constexpr unsigned long httpConnectTimeoutMs = 10000;
constexpr unsigned long httpRequestTimeoutMs = 20000;
constexpr unsigned long validUnixTime = 1704067200UL;  // 2024-01-01 UTC
constexpr char ntpServerPrimary[] = "pool.ntp.org";
constexpr char ntpServerSecondary[] = "time.google.com";

// Conservative OV2640 indoor defaults. Each value remains within the sensor
// driver's documented range and can be tuned after comparing the original JPEG
// (not only the TFT preview) under the intended lighting.
constexpr int sensorBrightness = 1;   // -2 to 2
constexpr int sensorContrast = -1;     // -2 to 2
constexpr int sensorSaturation = 0;   // -2 to 2
constexpr int sensorAutoExposureLevel = 2;  // -2 to 2
constexpr int sensorAdvancedExposure = 0;
constexpr gainceiling_t sensorGainCeiling = GAINCEILING_8X; // 從 4X 改為 8X 或 16X

// Compensate the visible active-area offset of the tested ST7735 module.
constexpr int displayTextOffsetX = 0;
constexpr int displayTextOffsetY = -3;
constexpr bool displayInverted = false;

}  // namespace AppConfig

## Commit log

2026-08-11 feat: 前端 web
    [tiger-camera-v1.csv]
2026-08-14 feat: 前後端分離
    [tiger-camera-v1.csv]
2026-08-14 feat: 更新前端樣式
2026-08-15 feat: web整合
    [tiger-camera-v1.csv]
2026-08-15 test(api): 完成所有後端 API 端點測試與驗證
2026-08-15 feat: 完成 Gate C0/H0, 建立正式 Gate H1 韌體
    [partitions.csv]
2026-08-16 feat: Gate H1 測試成功
2026-08-23 feat: Enhance camera firmware with networking and upload capabilities
    - Added independent networking configuration and management in `network_manager.h` and `network_manager.cpp`.
    - Introduced `upload_manager.h` and `upload_manager.cpp` to handle photo uploads with claim codes.
    - Implemented claim code display in `display_controller.h` and `display_controller.cpp`.
    - Updated `main.cpp` to manage new camera states for upload notices and claim readiness.
    - Enhanced configuration checks in `device_config.h` for WiFi and upload settings.
    - Added root CA certificate handling for Cloudflare R2 in `r2_root_ca.h`.
    - Improved error handling and user feedback in the photo processing frontend.
    - Update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
    [app_config.h, main.cpp, network_manager.cpp]
2026-08-23 feat: Update image retrieval process to return JPEG directly from backend and enhance user messaging for download failures
    [main.cpp]
2026-08-23 feat: 完成 L0
2026-08-24 feat(web): gallery 加入下載功能
    [partitions.csv, tiger-camera-v1.csv]
2026-08-24 feat: W0：Android Chrome 實機通過；I0：Android NFC 開啟 /create 與領取流程通過。
2026-08-24 Refactor device authentication to use fixed DEVICE_UPLOAD_TOKEN
    - Removed device credential management from admin API routes.
    - Updated device draft handling to utilize DEVICE_UPLOAD_TOKEN for authentication.
    - Simplified device-related database interactions by dropping device_id constraints.
    - Introduced DEVICE_UPLOAD_TOKEN validation in the backend.
    - Updated documentation to reflect changes in device authentication and API usage.
    - Removed unused device management functions from frontend admin panel.
    - Added migration script to adjust database schema for new authentication method.
2026-08-24 feat(docs): update project status and BOM documentation for P0 power components
    [tiger-camera-v1.csv]
2026-08-26 chore: 更新 README.md
2026-08-27 feat: 完成 Gate P0
    [tiger-camera-v1.csv]
2026-08-28 feat: 更新外殼尺寸
2026-08-30 feat: 更新 v1 模型 fix: 修正手機版照片後製樣式
    [v1.blend, v1.stl, 前蓋.stl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]
2026-08-30 feat: Update photo processing and filter presets for Canvas v3
    - Added new filter presets: mono-mochi, neon-party, sunny-milk, candy-pop, and lavender-dream.
    - Retired jungle-green filter; it is now only accepted for historical photos.
    - Updated processing options to support new frame layouts: portrait, landscape, and square.
    - Enhanced Canvas output to maintain aspect ratios without rotating images.
    - Modified API documentation and frontend components to reflect changes in filter presets and processing options.
    - Improved user interface for selecting filters and frame layouts in the photo processor.
    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
2026-08-30 chore: 整理專案結構
2026-08-30 feat: 更新 README.md
